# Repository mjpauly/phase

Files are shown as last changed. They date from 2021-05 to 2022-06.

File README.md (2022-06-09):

# Phase Keyboard

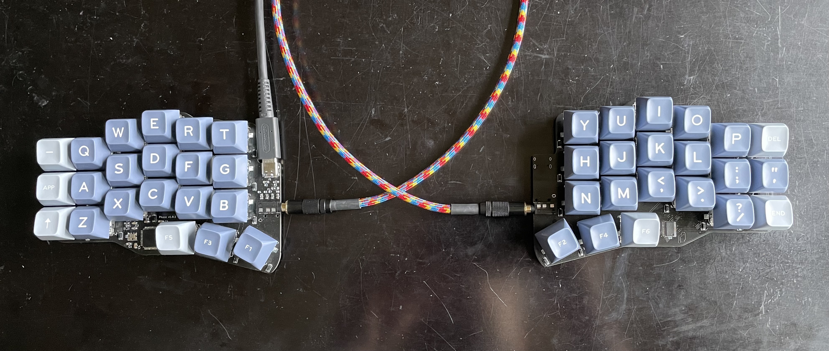
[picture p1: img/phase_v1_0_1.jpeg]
Phase v1.0.1


- Kyria stagger, Corne thumb cluster, Ferris-inspired electronics.
- USB-C
- Reversible PCB for use with both hands.
- MX-style key switch support with optional Kailh hot swap sockets.
- 42 keys.

A one-off moon-themed sand-cast aluminum case was also designed in Spring 2022. See [here](https://imgur.com/a/QfmxirT) for photos of the manufacturing process!

Phase Aluminum Case

## Versions

### Version 1.0.1

- Assembled and tested
- Fixes SDA/SCL swap
- Removes silkscreen art (just too cluttered)
- Gerbers are at `phase/JLCPCB_2022-01-29_v1_0_1.zip`.

### Version 1.0.0

- Manufactured with JLCPCB, built, and tested.
- SDA and SCL are swapped, so some rework is required. The traces need to be cut, soldermask has to be scraped away, and wires have to be soldered where the soldermask was removed. See the image at `img/phase_v1_0_0_rework.jpeg`. This is fixed in v1.0.1.
- Gerbers at `phase/JCLPCB_2020-09-21_v1_0_0.zip`.

## Firmware

Firmware can be found here: [https://github.com/mjpauly/qmk_firmware/tree/master/keyboards/phase](https://github.com/mjpauly/qmk_firmware/tree/master/keyboards/phase). It's not merged into mainline QMK, but if you want to use the design then I can make that happen.

## BOM

The BOM for SMD components can be found at `phase/bom-with-pns-lcsc.csv`. This lists the part numbers that can be purchased from [LCSC](https://lcsc.com). In addition to this, the following may also needed for a complete keyboard:
- TRRS connectors from [AliExpress](https://www.aliexpress.com/item/33029465106.html).
- A TRRS cable. [This one](https://www.amazon.com/gp/product/B019EHMN68?psc=1) is good.
- [Kailh hot swap sockets](https://kbdfans.com/products/mechanical-keyboard-switches-kailh-pcb-socket).
- MX style switches.
- Keycaps: 42x 1u, option for 2x 1.5u keycaps for the center-most thumb keys.
- USB-C cable.
- Rubber feet. [3M SJ5376](https://www.digikey.com/en/products/detail/3m/SJ5376/3866077) are tall enough to work with the hot swap sockets and narrow enough to fit in the pattern of keys.

## Part libraries

All non-standard parts are in the project library except for the keyswitch footprint `Kailh_socket_MX_optional_reversible` from [daprice](https://github.com/daprice/keyswitches.pretty). Credit also goes to [Keebio](https://github.com/keebio/Keebio-Parts.pretty) for the TRRS connector footprint `TRRS-PJ-320A-dual`.

## Silkscreen on v1.0.0

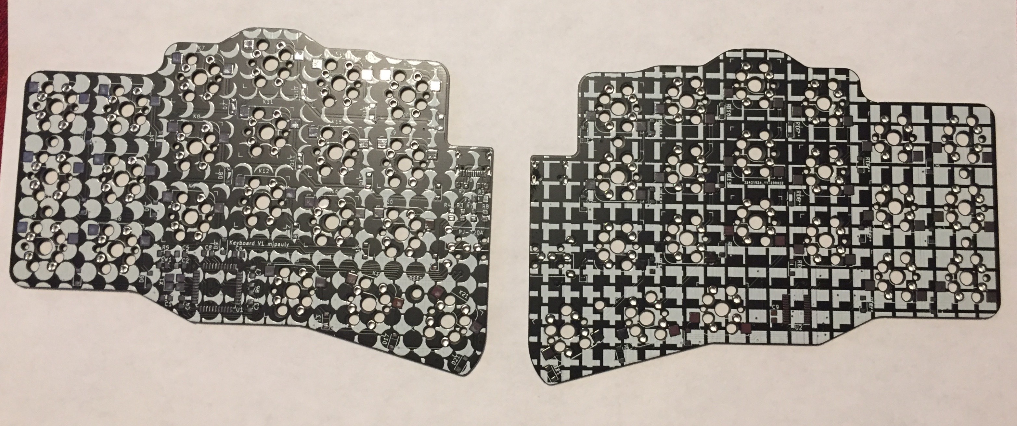
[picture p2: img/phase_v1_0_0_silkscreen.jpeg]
Silkscreen


The silkscreen is based on the following images generated with Processing. I felt like this made the PCB too cluttered, so it's removed in the latest version.

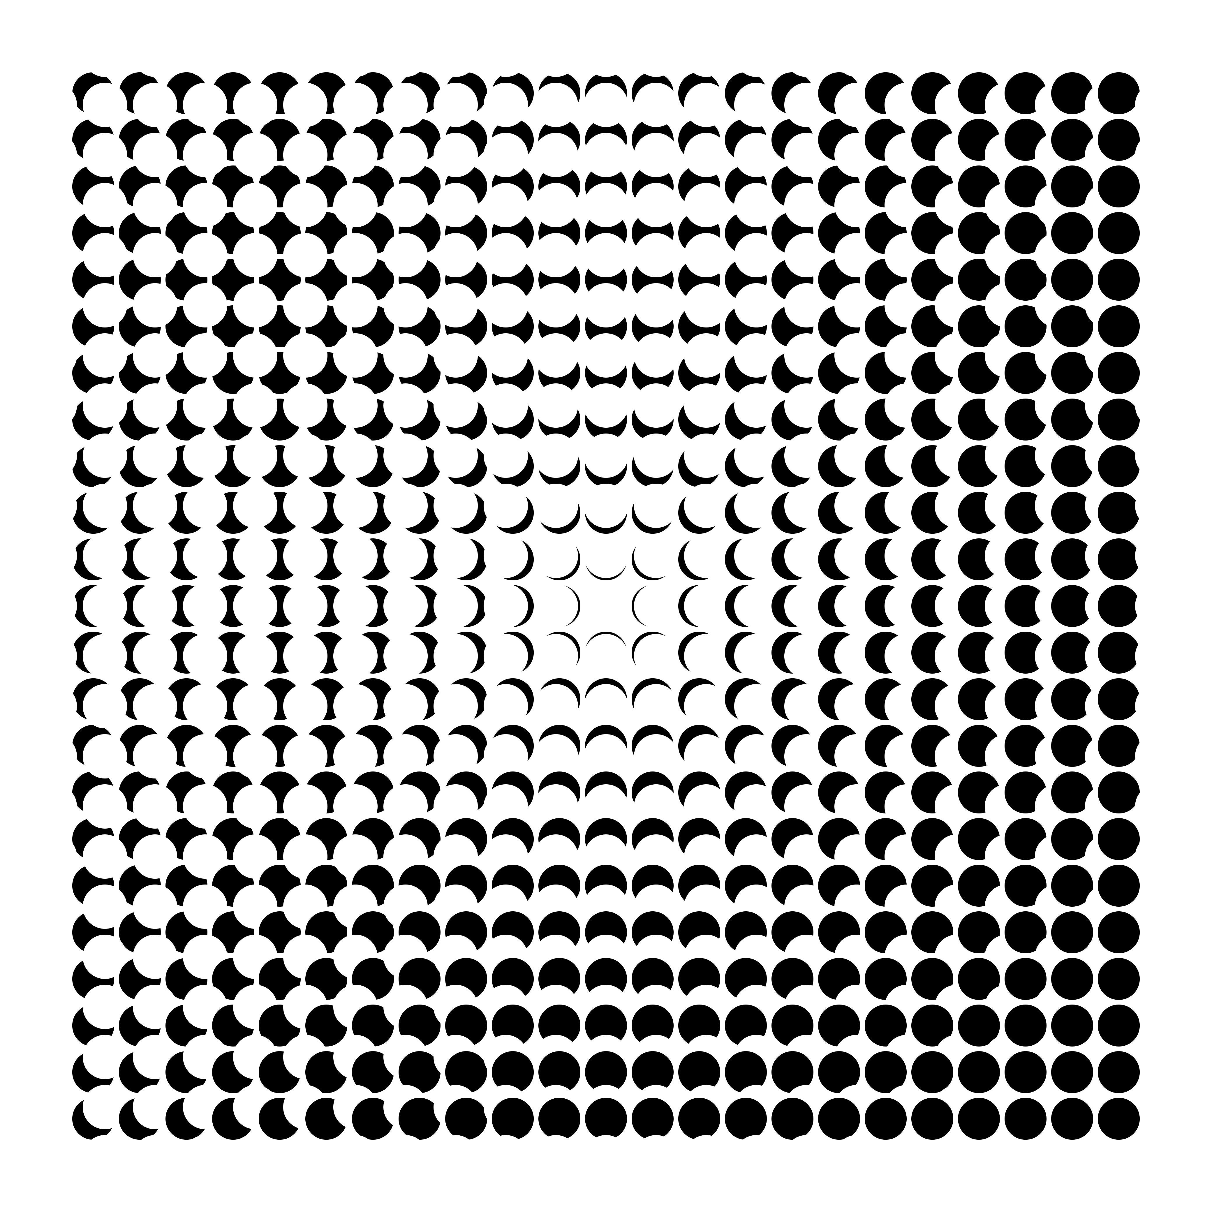
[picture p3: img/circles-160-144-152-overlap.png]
Circles


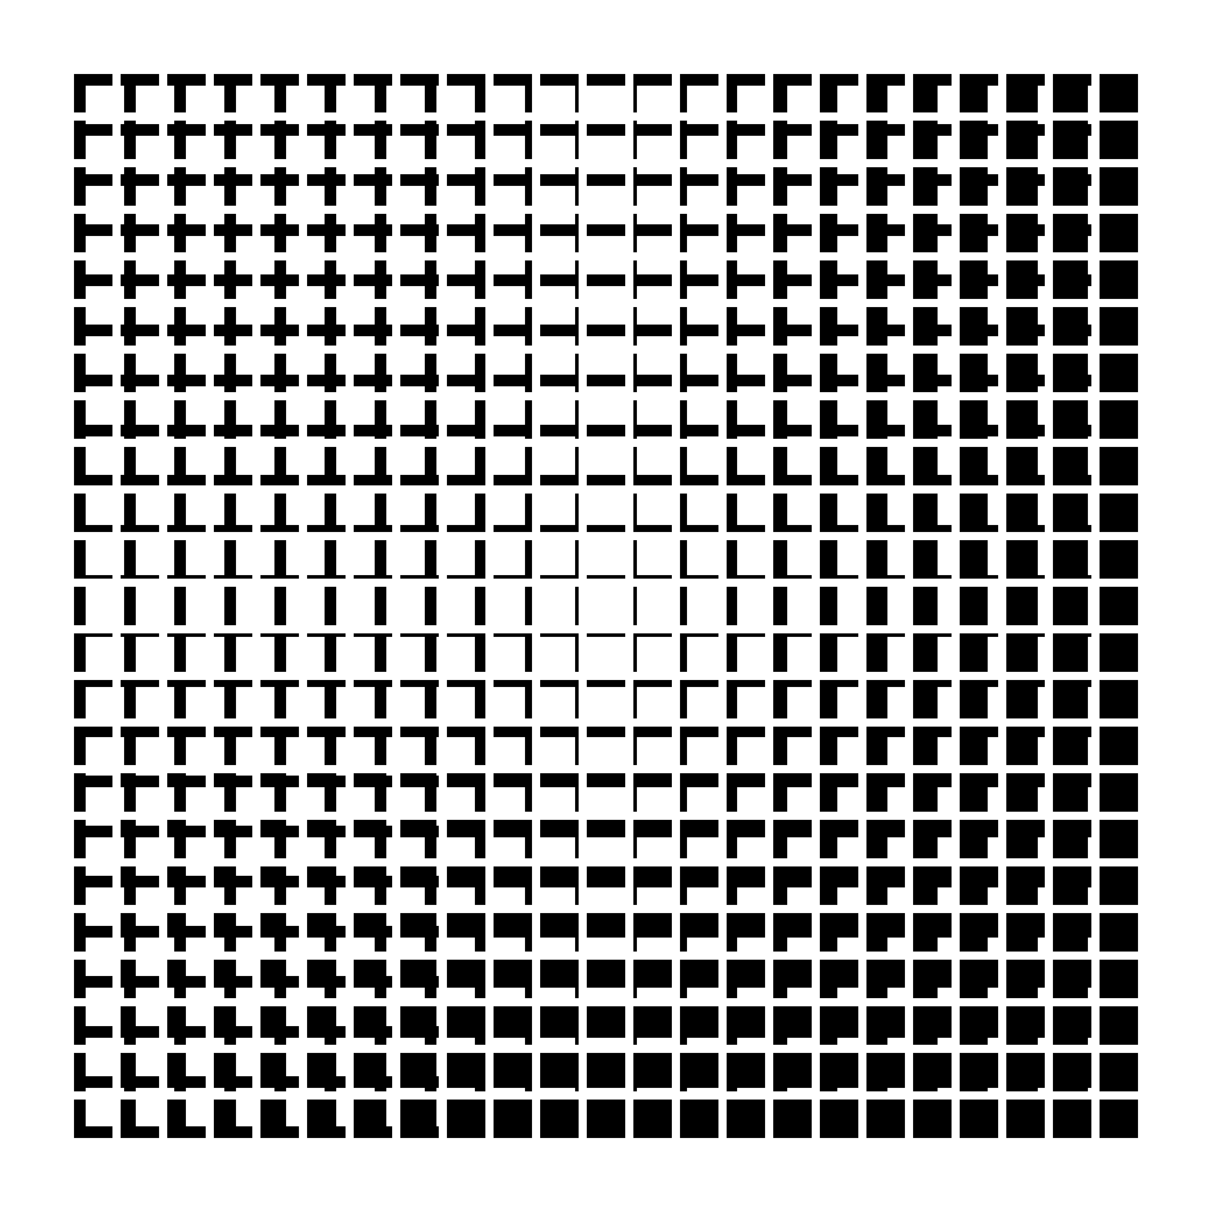
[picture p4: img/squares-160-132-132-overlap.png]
Squares


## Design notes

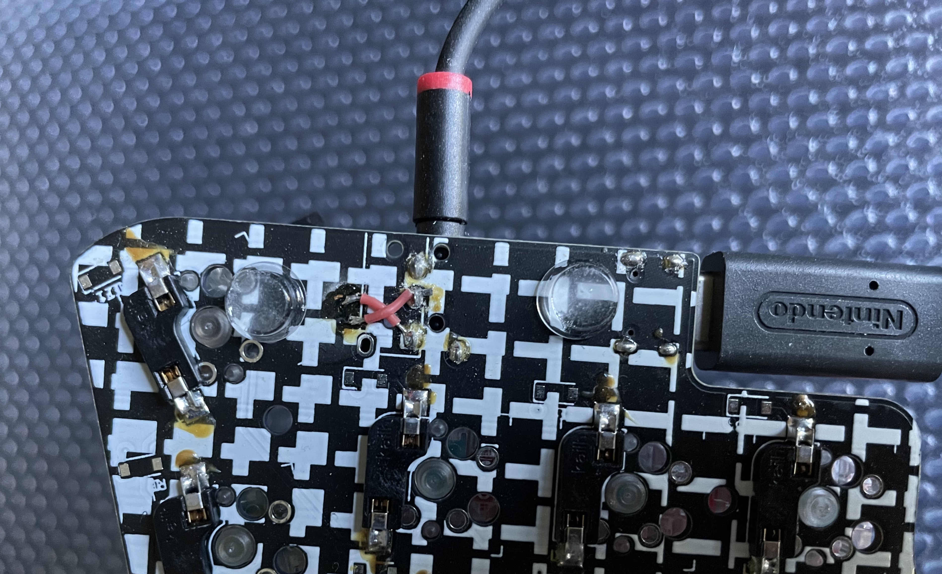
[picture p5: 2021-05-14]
img/phase_v1_0_0_rework.jpeg

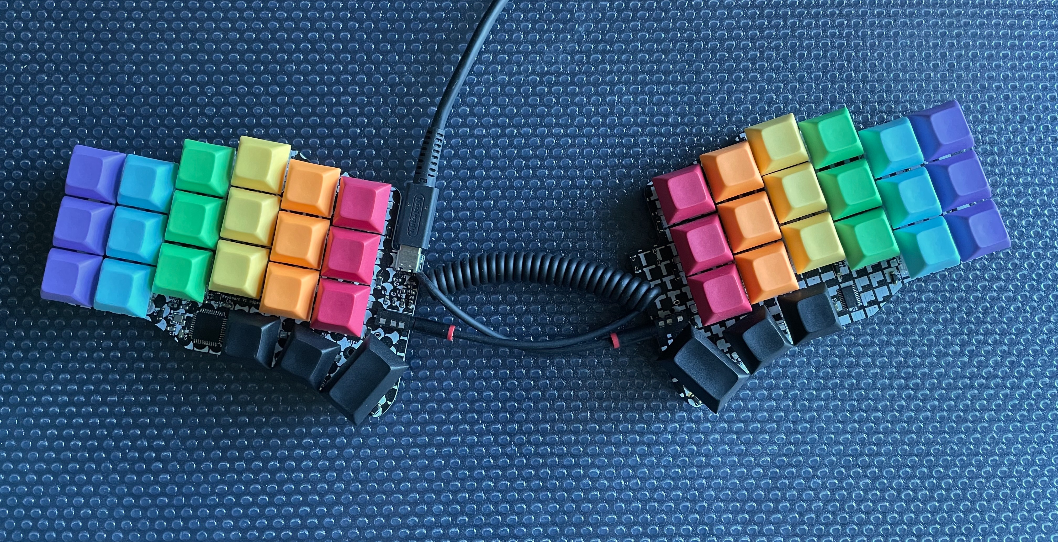
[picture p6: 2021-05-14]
img/phase_v1_0_0.jpeg

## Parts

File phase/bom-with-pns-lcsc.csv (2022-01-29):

Item | Qty | Reference(s) | Value | LibPart | Footprint | Datasheet | LCSC PN
1 | 2 | C1, C2 | 22p | Device:C_Small | Capacitor_SMD:C_0805_2012Metric_Pad1.15x1.40mm_HandSolder | ~ | C1804
2 | 5 | C3, C4, C5, C6, C9 | 0.1u | Device:C_Small | Capacitor_SMD:C_0805_2012Metric_Pad1.15x1.40mm_HandSolder | ~ | C49678
3 | 1 | C7 | 4.7u | Device:C_Small | Capacitor_SMD:C_0805_2012Metric_Pad1.15x1.40mm_HandSolder | ~ | C1779
4 | 1 | C8 | 1u | Device:C_Small | Capacitor_SMD:C_0805_2012Metric_Pad1.15x1.40mm_HandSolder | ~ | C28323
5 | 42 | D1, D2, D3, D4, D5, D6, D7, D8, D9, D10, D11, D12, D13, D14, D15, D16, D17, D18, D19, D20, D21 | D | Device:D | phase:D_SOD-123-dual | ~ | C81598
6 | 1 | F1 | 500mA | Device:Polyfuse | Fuse:Fuse_1206_3216Metric_Pad1.42x1.75mm_HandSolder | ~ | C151162
7 | 1 | J1 | USB_C_Receptacle_USB2.0 | Connector:USB_C_Receptacle_USB2.0 | Connector_USB:USB_C_Receptacle_HRO_TYPE-C-31-M-12 | https://www.usb.org/sites/default/files/documents/usb_type-c.zip | C165948
8 | 2 | J2 | AudioJack4 | Connector:AudioJack4 | phase:TRRS-PJ-320A-dual | ~
9 | 42 | K1, K2, K3, K4, K5, K6, K7, K8, K9, K10, K11, K12, K13, K14, K15, K16, K17, K18, K19, K20, K21 | KEYSW | keyboard_parts:KEYSW | keyswitches:Kailh_socket_MX_optional_reversible
10 | 2 | R1, R2 | 5.1k | Device:R_Small_US | Resistor_SMD:R_0805_2012Metric_Pad1.15x1.40mm_HandSolder | ~ | C27834
11 | 2 | R3, R4 | 22 | Device:R_Small_US | Resistor_SMD:R_0805_2012Metric_Pad1.15x1.40mm_HandSolder | ~ | C17561
12 | 2 | R5, R6 | 10k | Device:R_Small_US | Resistor_SMD:R_0805_2012Metric_Pad1.15x1.40mm_HandSolder | ~ | C17414
13 | 2 | R7, R8 | 4.7k | Device:R_Small_US | Resistor_SMD:R_0805_2012Metric_Pad1.15x1.40mm_HandSolder | ~ | C17673
15 | 1 | U1 | ATmega32U4-AU | MCU_Microchip_ATmega:ATmega32U4-AU | Package_QFP:TQFP-44_10x10mm_P0.8mm | http://ww1.microchip.com/downloads/en/DeviceDoc/Atmel-7766-8-bit-AVR-ATmega16U4-32U4_Datasheet.pdf | C44854
16 | 1 | U2 | PCA9555PW | Interface_Expansion:PCA9555PW | Package_SO:TSSOP-24_4.4x7.8mm_P0.65mm | https://www.nxp.com/docs/en/data-sheet/PCA9555.pdf | C128392
17 | 1 | X1 | Crystal_GND24_Small | Device:Crystal_GND24_Small | Crystal:Crystal_SMD_3225-4Pin_3.2x2.5mm_HandSoldering | ~ | C13738

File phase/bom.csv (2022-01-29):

Item | Qty | Reference(s) | Value | LibPart | Footprint | Datasheet
1 | 2 | C1, C2 | 22p | Device:C_Small | Capacitor_SMD:C_0805_2012Metric_Pad1.15x1.40mm_HandSolder | ~
2 | 5 | C3, C4, C5, C6, C9 | 0.1u | Device:C_Small | Capacitor_SMD:C_0805_2012Metric_Pad1.15x1.40mm_HandSolder | ~
3 | 1 | C7 | 4.7u | Device:C_Small | Capacitor_SMD:C_0805_2012Metric_Pad1.15x1.40mm_HandSolder | ~
4 | 1 | C8 | 1u | Device:C_Small | Capacitor_SMD:C_0805_2012Metric_Pad1.15x1.40mm_HandSolder | ~
5 | 21 | D1, D2, D3, D4, D5, D6, D7, D8, D9, D10, D11, D12, D13, D14, D15, D16, D17, D18, D19, D20, D21 | D | Device:D | phase:D_SOD-123-dual | ~
6 | 1 | F1 | 500mA | Device:Polyfuse | Fuse:Fuse_1206_3216Metric_Pad1.42x1.75mm_HandSolder | ~
7 | 1 | J1 | USB_C_Receptacle_USB2.0 | Connector:USB_C_Receptacle_USB2.0 | Connector_USB:USB_C_Receptacle_HRO_TYPE-C-31-M-12 | https://www.usb.org/sites/default/files/documents/usb_type-c.zip
8 | 1 | J2 | AudioJack4 | Connector:AudioJack4 | phase:TRRS-PJ-320A-dual | ~
9 | 21 | K1, K2, K3, K4, K5, K6, K7, K8, K9, K10, K11, K12, K13, K14, K15, K16, K17, K18, K19, K20, K21 | KEYSW | keyboard_parts:KEYSW | keyswitches:Kailh_socket_MX_optional_reversible
10 | 2 | R1, R2 | 5.1k | Device:R_Small_US | Resistor_SMD:R_0805_2012Metric_Pad1.15x1.40mm_HandSolder | ~
11 | 2 | R3, R4 | 22 | Device:R_Small_US | Resistor_SMD:R_0805_2012Metric_Pad1.15x1.40mm_HandSolder | ~
12 | 2 | R5, R6 | 10k | Device:R_Small_US | Resistor_SMD:R_0805_2012Metric_Pad1.15x1.40mm_HandSolder | ~
13 | 2 | R7, R8 | 4.7k | Device:R_Small_US | Resistor_SMD:R_0805_2012Metric_Pad1.15x1.40mm_HandSolder | ~
14 | 1 | SW1 | SW_Push | Switch:SW_Push | Connector_PinHeader_1.00mm:PinHeader_1x02_P1.00mm_Vertical | ~
15 | 1 | U1 | ATmega32U4-AU | MCU_Microchip_ATmega:ATmega32U4-AU | Package_QFP:TQFP-44_10x10mm_P0.8mm | http://ww1.microchip.com/downloads/en/DeviceDoc/Atmel-7766-8-bit-AVR-ATmega16U4-32U4_Datasheet.pdf
16 | 1 | U2 | PCA9555PW | Interface_Expansion:PCA9555PW | Package_SO:TSSOP-24_4.4x7.8mm_P0.65mm | https://www.nxp.com/docs/en/data-sheet/PCA9555.pdf
17 | 1 | X1 | Crystal_GND24_Small | Device:Crystal_GND24_Small | Crystal:Crystal_SMD_3225-4Pin_3.2x2.5mm_HandSoldering | ~

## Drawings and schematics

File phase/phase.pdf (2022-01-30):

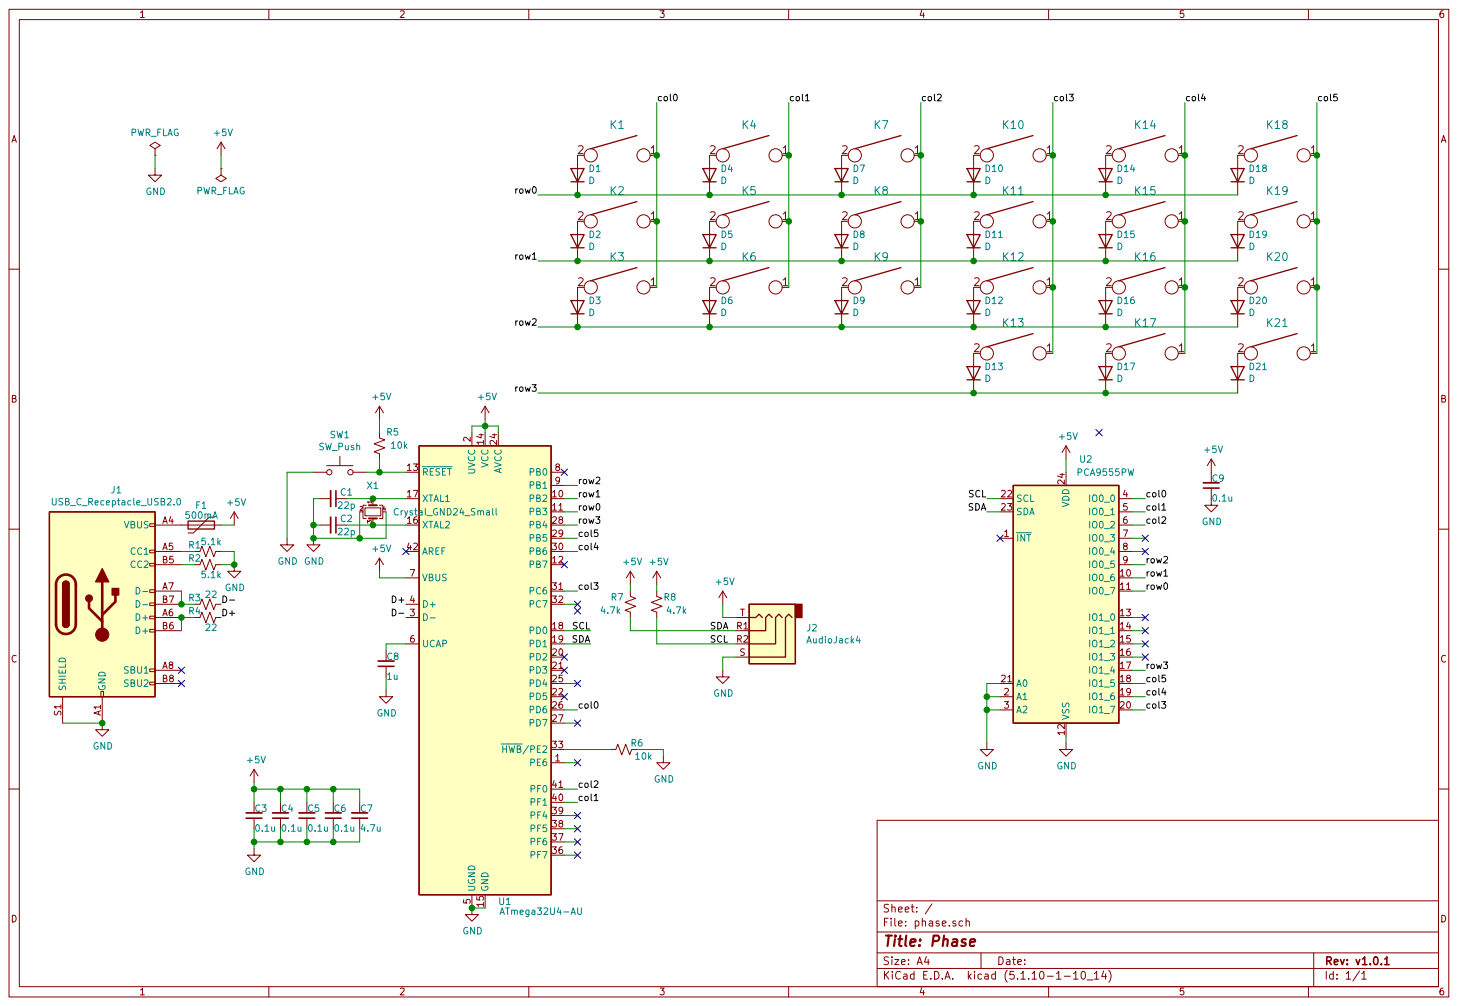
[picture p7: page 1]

2 PD2 20 PD3 21 PD5 22 AVCC 24 PD4 25 PD6 26 PD7 27 PB4 28 PB5 29 D- 3 PB6 30 PC6 31 PC7 32 HWB/PE2 33 PF7 36 PF6 37 PF5 38 PF4 39 D+ 4 PF1 40 PF0 41 AREF 42 UGND

5 UCAP 6 VBUS 7 PB0 8 PB1 9 U1ATmega32U4-AU GND A1 VBUS A4 CC1 A5 D+ A6 D- A7 SBU1 A8 CC2 B5 D+ B6 D- B7 SBU2 B8 SHIELD S1

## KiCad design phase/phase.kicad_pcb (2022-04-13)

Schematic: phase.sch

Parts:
C1, C2: 22p; C_0805_2012Metric_Pad1.15x1.40mm_HandSolder
C3, C4, C5, C6, C9: 0.1u; C_0805_2012Metric_Pad1.15x1.40mm_HandSolder
C7: 4.7u; C_0805_2012Metric_Pad1.15x1.40mm_HandSolder
C8: 1u; C_0805_2012Metric_Pad1.15x1.40mm_HandSolder
D1, D2, D3, D4, D5, D6, D7, D8, D9, D10, D11, D12, D13, D14, D15, D16, D17, D18, D19, D20, D21: D; D_SOD-123-dual
F1: 500mA; Fuse_1206_3216Metric_Pad1.42x1.75mm_HandSolder
J1: USB_C_Receptacle_USB2.0; USB_C_Receptacle_HRO_TYPE-C-31-M-12
J2: AudioJack4; TRRS-PJ-320A-dual
K1, K2, K3, K4, K5, K6, K7, K8, K9, K10, K11, K12, K13, K14, K15, K16, K17, K18, K19, K20, K21: KEYSW; Kailh_socket_MX_optional_reversible
R1, R2: 5.1k; R_0805_2012Metric_Pad1.15x1.40mm_HandSolder
R3, R4: 22; R_0805_2012Metric_Pad1.15x1.40mm_HandSolder
R5, R6: 10k; R_0805_2012Metric_Pad1.15x1.40mm_HandSolder
R7, R8: 4.7k; R_0805_2012Metric_Pad1.15x1.40mm_HandSolder
SW1: SW_Push; R_0805_2012Metric_Pad1.15x1.40mm_HandSolder
U1: ATmega32U4-AU; TQFP-44_10x10mm_P0.8mm
U2: PCA9555PW; TSSOP-24_4.4x7.8mm_P0.65mm
X1: Crystal_GND24_Small; Crystal_SMD_3225-4Pin_3.2x2.5mm_HandSoldering

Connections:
+5V: C3.2, C4.2, C5.2, C6.2, C7.2, C9.2, F1.1, J2.T, R5.2, R7.2, R8.2, U1.2, U1.7, U1.14, U1.24, U1.34, U1.44, U2.24
/D+: R4.1, U1.4
/D-: R3.1, U1.3
/SCL: J2.R2, R8.1, U1.18, U2.22
/SDA: J2.R1, R7.1, U1.19, U2.23
/col0: K1.1, K2.1, K3.1, U1.26, U2.4
/col1: K4.1, K5.1, K6.1, U1.40, U2.5
/col2: K7.1, K8.1, K9.1, U1.41, U2.6
/col3: K10.1, K11.1, K12.1, K13.1, U1.31, U2.20
/col4: K14.1, K15.1, K16.1, K17.1, U1.30, U2.19
/col5: K18.1, K19.1, K20.1, K21.1, U1.29, U2.18
/row0: D1.1, D4.1, D7.1, D10.1, D14.1, D18.1, U1.11, U2.11
/row1: D2.1, D5.1, D8.1, D11.1, D15.1, D19.1, U1.10, U2.10
/row2: D3.1, D6.1, D9.1, D12.1, D16.1, D20.1, U1.9, U2.9
/row3: D13.1, D17.1, D21.1, U1.28, U2.17
GND: C1.2, C2.2, C3.1, C4.1, C5.1, C6.1, C7.1, C8.1, C9.1, J1.A1 (GND), J1.A12 (GND), J1.B1 (GND), J1.B12 (GND), J1.S1 (SHIELD), J2.S, R1.1, R2.1, R6.1, SW1.1, U1.5, U1.15, U1.23, U1.35, U1.43, U2.2, U2.3, U2.12, U2.21, X1.2, X1.4
unnamed: C1.1, U1.17, X1.1
unnamed: C2.1, U1.16, X1.3
unnamed: C8.2, U1.6
unnamed: D1.2, K1.2
unnamed: D2.2, K2.2
unnamed: D3.2, K3.2
unnamed: D4.2, K4.2
unnamed: D5.2, K5.2
unnamed: D6.2, K6.2
unnamed: D7.2, K7.2
unnamed: D8.2, K8.2
unnamed: D9.2, K9.2
unnamed: D10.2, K10.2
unnamed: D11.2, K11.2
unnamed: D12.2, K12.2
unnamed: D13.2, K13.2
unnamed: D14.2, K14.2
unnamed: D15.2, K15.2
unnamed: D16.2, K16.2
unnamed: D17.2, K17.2
unnamed: D18.2, K18.2
unnamed: D19.2, K19.2
unnamed: D20.2, K20.2
unnamed: D21.2, K21.2
unnamed: F1.2, J1.A4 (VBUS), J1.A9 (VBUS), J1.B4 (VBUS), J1.B9 (VBUS)
unnamed: J1.A5 (CC1), R1.2
unnamed: J1.A6 (D+), J1.B6 (D+), R4.2
unnamed: J1.A7 (D-), J1.B7 (D-), R3.2
unnamed: J1.B5 (CC2), R2.2
unnamed: R5.1, SW1.2, U1.13
unnamed: R6.2, U1.33

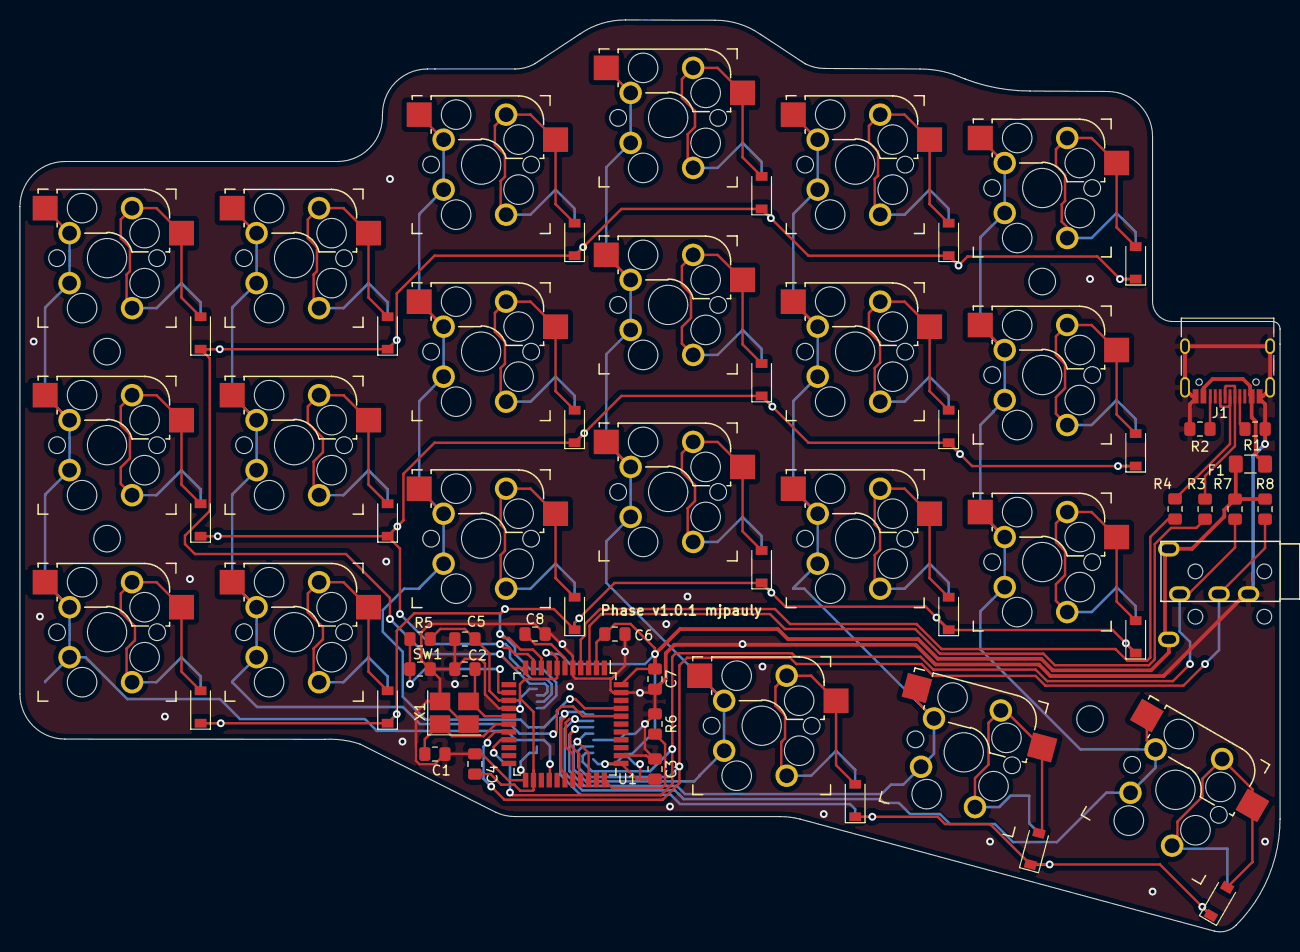
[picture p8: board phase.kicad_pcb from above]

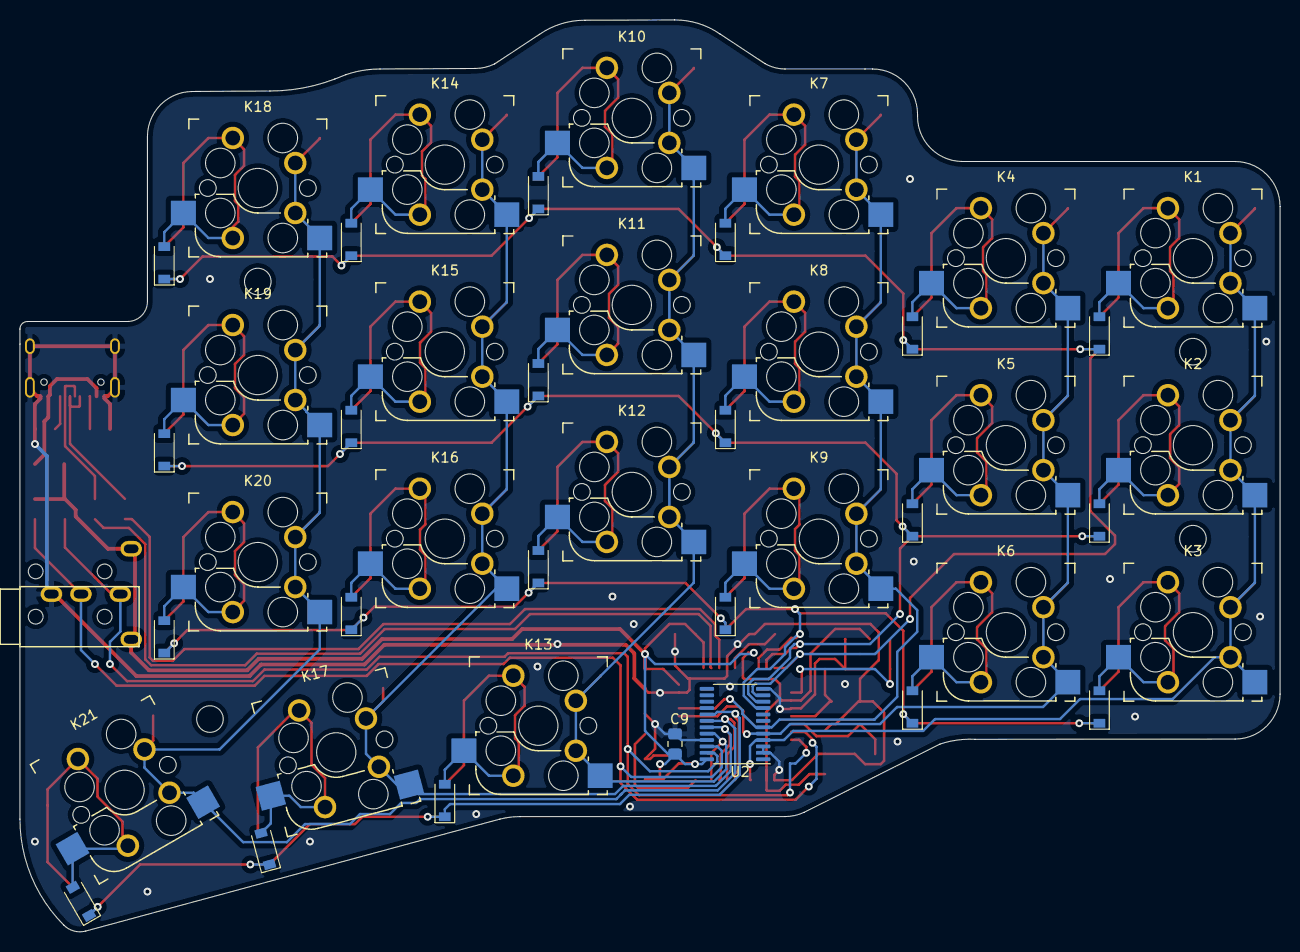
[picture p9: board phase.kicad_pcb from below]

Board: 2 copper layers, 128.0 x 92.6 mm, 66 parts (2 on the bottom side), 47 nets.

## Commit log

2021-05-14 add phase v1 files
    [bom-with-pns-lcsc.csv, bom.csv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]
2022-01-29 renamed files to remove version number, add gitignore
    [bom-with-pns-lcsc.csv, bom.csv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]
2022-01-30 fix sda/scl swap, remove silkscreen art and unneeded ref des
    [phase-B_Cu.gbr, phase-B_Mask.gbr, phase-B_Paste.gbr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]
2022-04-13 add 3d model
    [phase.kicad_pcb]
2022-06-09 update with v1.0.1 results, add info about one-off aluminum case project
